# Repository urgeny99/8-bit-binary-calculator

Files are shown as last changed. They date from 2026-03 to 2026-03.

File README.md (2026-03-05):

# 8-bit-binary-calculator
## This is an 8-bit adder that adds two 8-bit numbers together (255+255).

### How It Works & Parts Used:

- 4x quad XOR gates (SN74HC86)
- 4x quad AND gates (SN74HC08)
- 2x quad OR gates (SN74HC32)
- 2x DIP switch x08
- 11x Decoupling capacitors 
- 9x single color LEDs for showing the output
- 25x resistors for setting switches Low and protecting LEDs (9x 1k; 16x 100k)
- 1x screw terminal for connecting to power

#### HOW IT WORKS

The adder works by having 8 + 8 inputs (A0-A7; B0-B7) and taking them into half and full adders.
Use the DIP-switches to set the input values, and read LED output.
The Half adder looks like this | And this is a Full adder 
:------:|:---------:
 | 



# BOM



Shematic   | PCB | 3D model
:-------------:|:-----------:|:-----------:
 |  |

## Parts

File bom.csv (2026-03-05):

Designator | Footprint | Quantity | Value | LCSC Part # | Link to parts
AND1, AND2, AND3, AND4 | SO-14_3.9x8.65mm_P1.27mm | 4 | SN74HC08N | C5217243 | https://www.lcsc.com/product-detail/C5217243.html
C1, C11, C2, C3, C4, C5, C6, C7, C8, C9 | 0603 | 10 | 0.1uF | C14663 | https://www.lcsc.com/product-detail/C14663.html
C10 | 0603 | 1 | 10uF | C19702 | https://www.lcsc.com/product-detail/C19702.html
D1, D2, D3, D4, D5, D6, D7, D8, D9 | 0805 | 9 | LED | C84260 | https://www.lcsc.com/product-detail/C84260.html
J1 | TerminalBlock_Phoenix_MKDS-1,5-2-5.08_1x02_P5.08mm_Horizontal | 1 | Screw_Terminal_01x02 | C5183929 | https://www.lcsc.com/product-detail/C5183929.html
OR1, OR2 | SO-14_3.9x8.65mm_P1.27mm | 2 | SN74HC32N | C2869657 | https://www.lcsc.com/product-detail/C2869657.html
R1, R2, R3, R4, R5, R6, R7, R8, R9 | 0603 | 9 | 1k | C22548 | https://www.lcsc.com/product-detail/C22548.html
R10, R11, R12, R13, R14, R15, R16, R17, R18, R19, R20, R21, R22, R23, R24, R25 | 0603 | 16 | 100k | C14675 | https://www.lcsc.com/product-detail/C14675.html
SW1, SW2 | SW_DIP_SPSTx08_Slide_9.78x22.5mm_W7.62mm_P2.54mm | 2 | SW_DIP_x08 | no Parts found
XOR1, XOR2, XOR3, XOR4 | SO-14_3.9x8.65mm_P1.27mm | 4 | SN74HC86N | C2860577 | https://www.lcsc.com/product-detail/C2860577.html

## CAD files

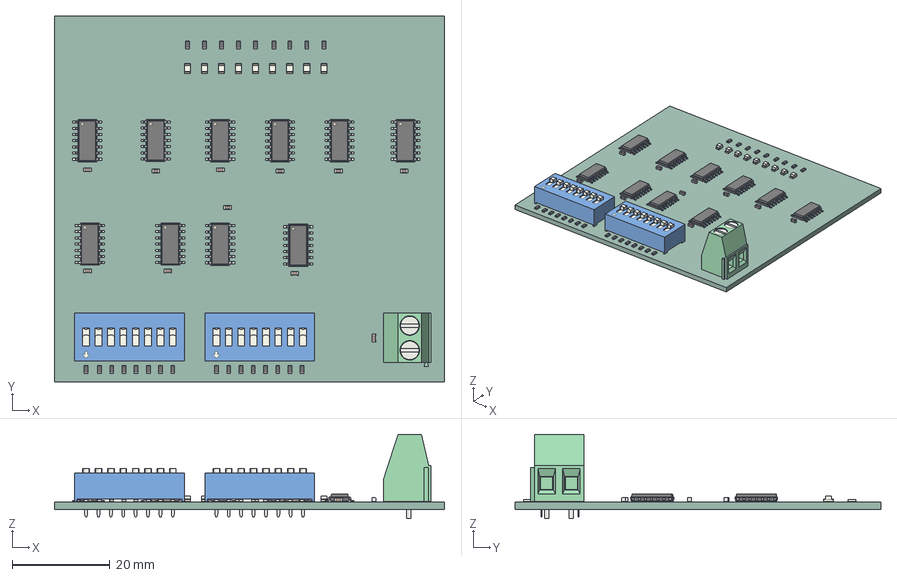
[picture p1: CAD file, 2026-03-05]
PCB-Design/8-bit calculator.step
80.0 x 75.0 x 17.3 mm
LED_0805_2012Metric x 9
R_0603_1608Metric x 25
SO-14_3.9x8.65mm_P1.27mm x 10
SW_DIP_SPSTx08_Slide_9.78x22.5mm_W7.62mm_P2.54mm x 2
TerminalBlock_Phoenix_MKDS-1,5-2-5.08_1x02_P5.08mm_Horizontal
C_0603_1608Metric x 11
8-bit calculator_PCB

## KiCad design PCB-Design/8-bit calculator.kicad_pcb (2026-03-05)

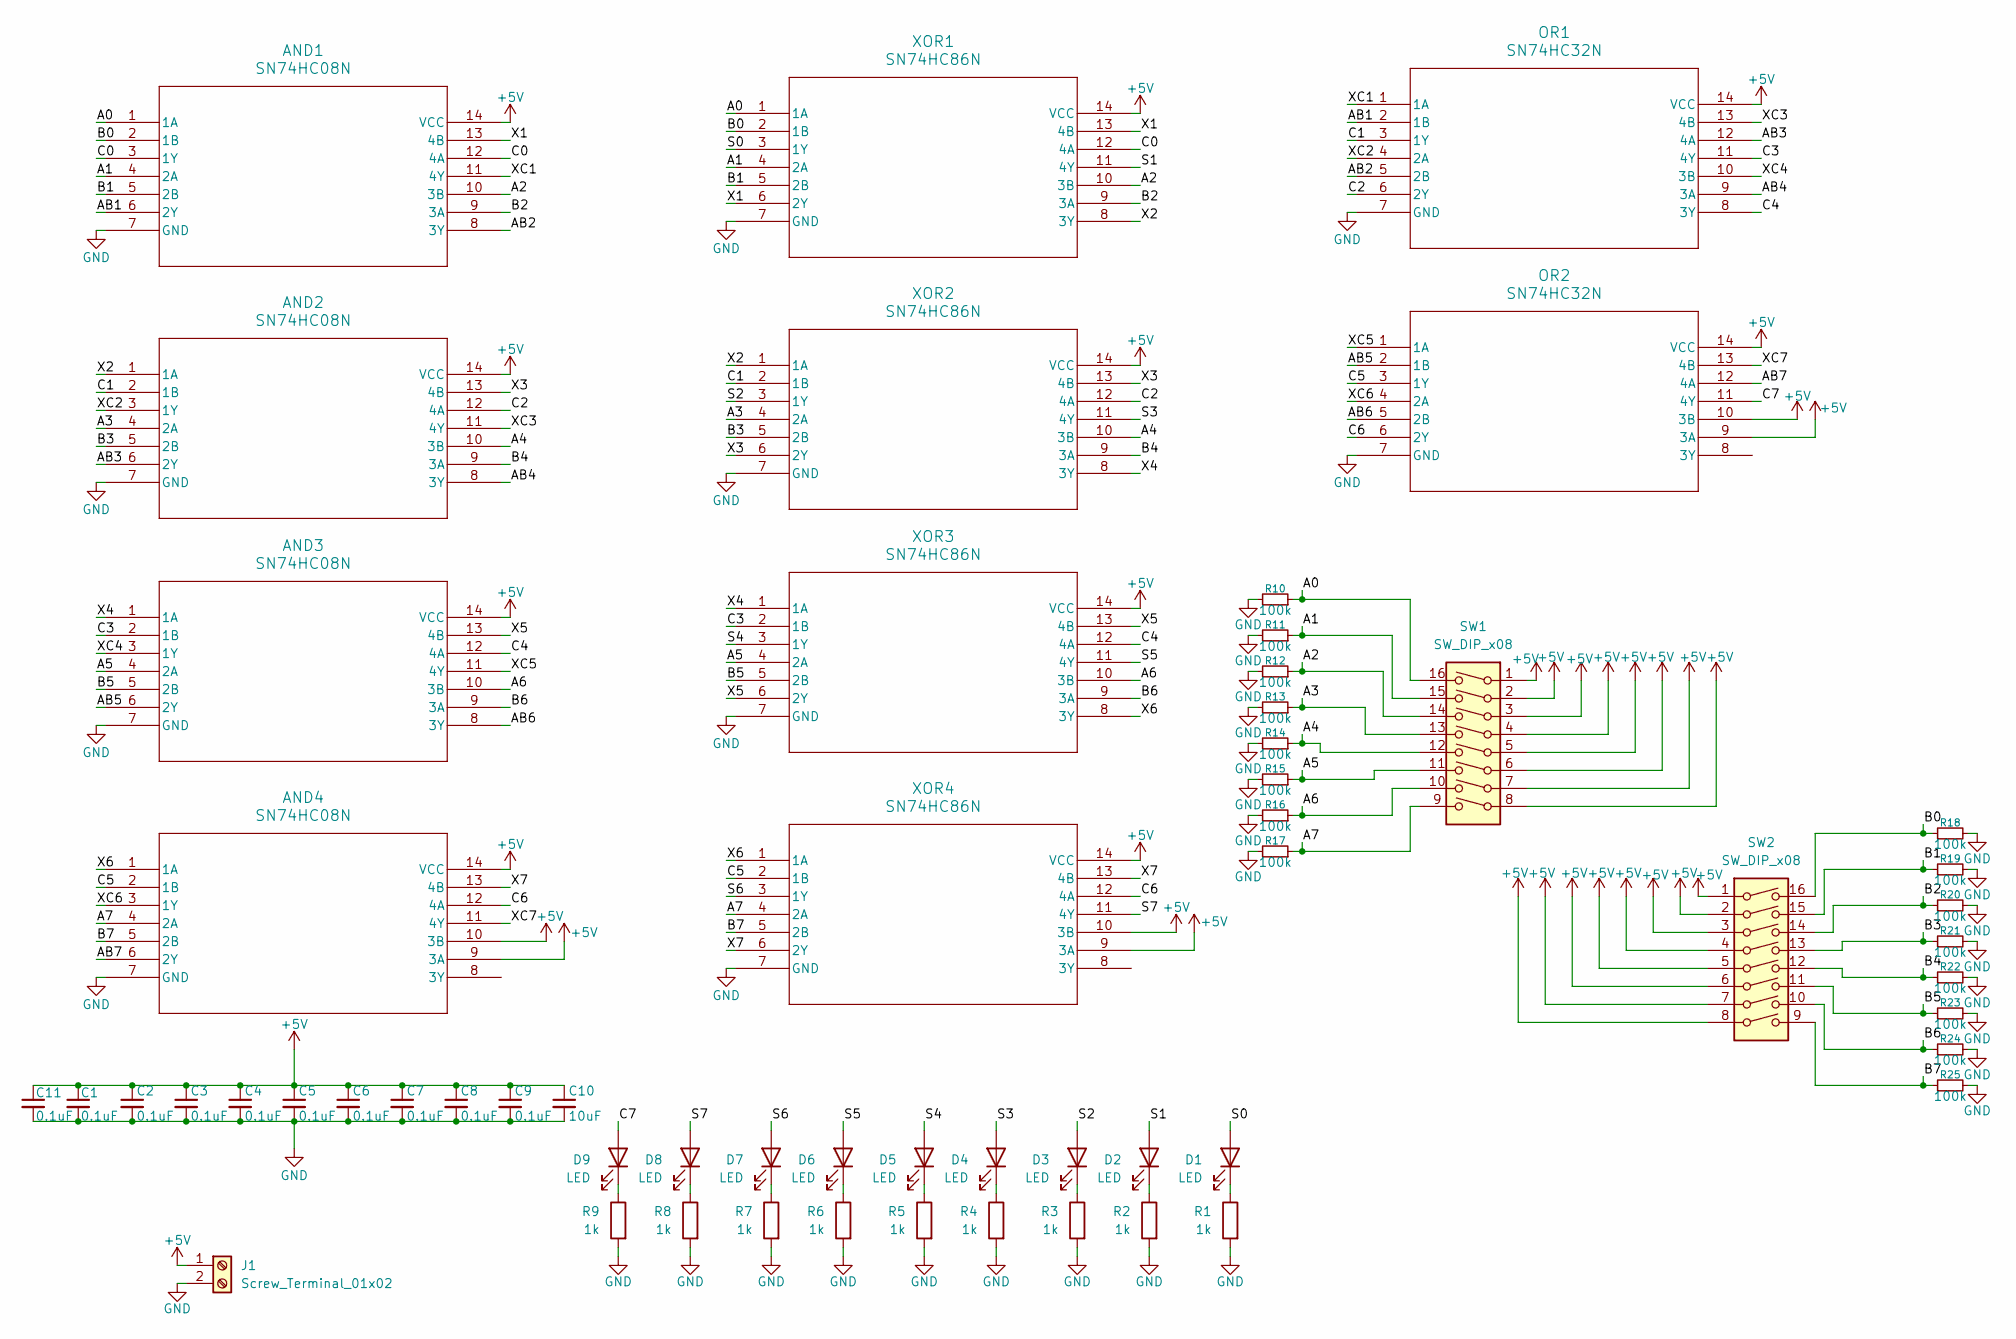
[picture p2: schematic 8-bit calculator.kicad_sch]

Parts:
AND1, AND2, AND3, AND4: SN74HC08N; SO-14_3.9x8.65mm_P1.27mm
C1, C2, C3, C4, C5, C6, C7, C8, C9, C11: 0.1uF; C_0603_1608Metric
C10: 10uF; C_0603_1608Metric
D1, D2, D3, D4, D5, D6, D7, D8, D9: LED; LED_0805_2012Metric
J1: Screw_Terminal_01x02; TerminalBlock_Phoenix_MKDS-1,5-2-5.08_1x02_P5.08mm_Horizont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
OR1, OR2: SN74HC32N; SO-14_3.9x8.65mm_P1.27mm
R1, R2, R3, R4, R5, R6, R7, R8, R9: 1k; R_0603_1608Metric
R10, R11, R12, R13, R14, R15, R16, R17, R18, R19, R20, R21, R22, R23, R24, R25: 100k; R_0603_1608Metric
SW1, SW2: SW_DIP_x08; SW_DIP_SPSTx08_Slide_9.78x22.5mm_W7.62mm_P2.54mm
XOR1, XOR2, XOR3, XOR4: SN74HC86N; SO-14_3.9x8.65mm_P1.27mm

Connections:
+5V: AND1.14 (VCC), AND2.14 (VCC), AND3.14 (VCC), AND4.9 (3A), AND4.10 (3B), AND4.14 (VCC), C1.1, C2.1, C3.1, C4.1, C5.1, C6.1, C7.1, C8.1, C9.1, C10.1, C11.1, J1.1, OR1.14 (VCC), OR2.9 (3A), OR2.10 (3B), OR2.14 (VCC), SW1.1, SW1.2, SW1.3, SW1.4, SW1.5, SW1.6, SW1.7, SW1.8, SW2.1, SW2.2, SW2.3, SW2.4, SW2.5, SW2.6, SW2.7, SW2.8, XOR1.14 (VCC), XOR2.14 (VCC), XOR3.14 (VCC), XOR4.9 (3A), XOR4.10 (3B), XOR4.14 (VCC)
/A0: AND1.1 (1A), R10.1, SW1.16, XOR1.1 (1A)
/A1: AND1.4 (2A), R11.1, SW1.15, XOR1.4 (2A)
/A2: AND1.10 (3B), R12.1, SW1.14, XOR1.10 (3B)
/A3: AND2.4 (2A), R13.1, SW1.13, XOR2.4 (2A)
/A4: AND2.10 (3B), R14.1, SW1.12, XOR2.10 (3B)
/A5: AND3.4 (2A), R15.1, SW1.11, XOR3.4 (2A)
/A6: AND3.10 (3B), R16.1, SW1.10, XOR3.10 (3B)
/A7: AND4.4 (2A), R17.1, SW1.9, XOR4.4 (2A)
/AB1: AND1.6 (2Y), OR1.2 (1B)
/AB2: AND1.8 (3Y), OR1.5 (2B)
/AB3: AND2.6 (2Y), OR1.12 (4A)
/AB4: AND2.8 (3Y), OR1.9 (3A)
/AB5: AND3.6 (2Y), OR2.2 (1B)
/AB6: AND3.8 (3Y), OR2.5 (2B)
/AB7: AND4.6 (2Y), OR2.12 (4A)
/B0: AND1.2 (1B), R18.1, SW2.16, XOR1.2 (1B)
/B1: AND1.5 (2B), R19.1, SW2.15, XOR1.5 (2B)
/B2: AND1.9 (3A), R20.1, SW2.14, XOR1.9 (3A)
/B3: AND2.5 (2B), R21.1, SW2.13, XOR2.5 (2B)
/B4: AND2.9 (3A), R22.1, SW2.12, XOR2.9 (3A)
/B5: AND3.5 (2B), R23.1, SW2.11, XOR3.5 (2B)
/B6: AND3.9 (3A), R24.1, SW2.10, XOR3.9 (3A)
/B7: AND4.5 (2B), R25.1, SW2.9, XOR4.5 (2B)
/C0: AND1.3 (1Y), AND1.12 (4A), XOR1.12 (4A)
/C1: AND2.2 (1B), OR1.3 (1Y), XOR2.2 (1B)
/C2: AND2.12 (4A), OR1.6 (2Y), XOR2.12 (4A)
/C3: AND3.2 (1B), OR1.11 (4Y), XOR3.2 (1B)
/C4: AND3.12 (4A), OR1.8 (3Y), XOR3.12 (4A)
/C5: AND4.2 (1B), OR2.3 (1Y), XOR4.2 (1B)
/C6: AND4.12 (4A), OR2.6 (2Y), XOR4.12 (4A)
/C7: D9.2 (A), OR2.11 (4Y)
/S0: D1.2 (A), XOR1.3 (1Y)
/S1: D2.2 (A), XOR1.11 (4Y)
/S2: D3.2 (A), XOR2.3 (1Y)
/S3: D4.2 (A), XOR2.11 (4Y)
/S4: D5.2 (A), XOR3.3 (1Y)
/S5: D6.2 (A), XOR3.11 (4Y)
/S6: D7.2 (A), XOR4.3 (1Y)
/S7: D8.2 (A), XOR4.11 (4Y)
/X1: AND1.13 (4B), XOR1.6 (2Y), XOR1.13 (4B)
/X2: AND2.1 (1A), XOR1.8 (3Y), XOR2.1 (1A)
/X3: AND2.13 (4B), XOR2.6 (2Y), XOR2.13 (4B)
/X4: AND3.1 (1A), XOR2.8 (3Y), XOR3.1 (1A)
/X5: AND3.13 (4B), XOR3.6 (2Y), XOR3.13 (4B)
/X6: AND4.1 (1A), XOR3.8 (3Y), XOR4.1 (1A)
/X7: AND4.13 (4B), XOR4.6 (2Y), XOR4.13 (4B)
/XC1: AND1.11 (4Y), OR1.1 (1A)
/XC2: AND2.3 (1Y), OR1.4 (2A)
/XC3: AND2.11 (4Y), OR1.13 (4B)
/XC4: AND3.3 (1Y), OR1.10 (3B)
/XC5: AND3.11 (4Y), OR2.1 (1A)
/XC6: AND4.3 (1Y), OR2.4 (2A)
/XC7: AND4.11 (4Y), OR2.13 (4B)
GND: AND1.7 (GND), AND2.7 (GND), AND3.7 (GND), AND4.7 (GND), C1.2, C2.2, C3.2, C4.2, C5.2, C6.2, C7.2, C8.2, C9.2, C10.2, C11.2, J1.2, OR1.7 (GND), OR2.7 (GND), R1.2, R2.2, R3.2, R4.2, R5.2, R6.2, R7.2, R8.2, R9.2, R10.2, R11.2, R12.2, R13.2, R14.2, R15.2, R16.2, R17.2, R18.2, R19.2, R20.2, R21.2, R22.2, R23.2, R24.2, R25.2, XOR1.7 (GND), XOR2.7 (GND), XOR3.7 (GND), XOR4.7 (GND)
unnamed: D1.1 (K), R1.1
unnamed: D2.1 (K), R2.1
unnamed: D3.1 (K), R3.1
unnamed: D4.1 (K), R4.1
unnamed: D5.1 (K), R5.1
unnamed: D6.1 (K), R6.1
unnamed: D7.1 (K), R7.1
unnamed: D8.1 (K), R8.1
unnamed: D9.1 (K), R9.1

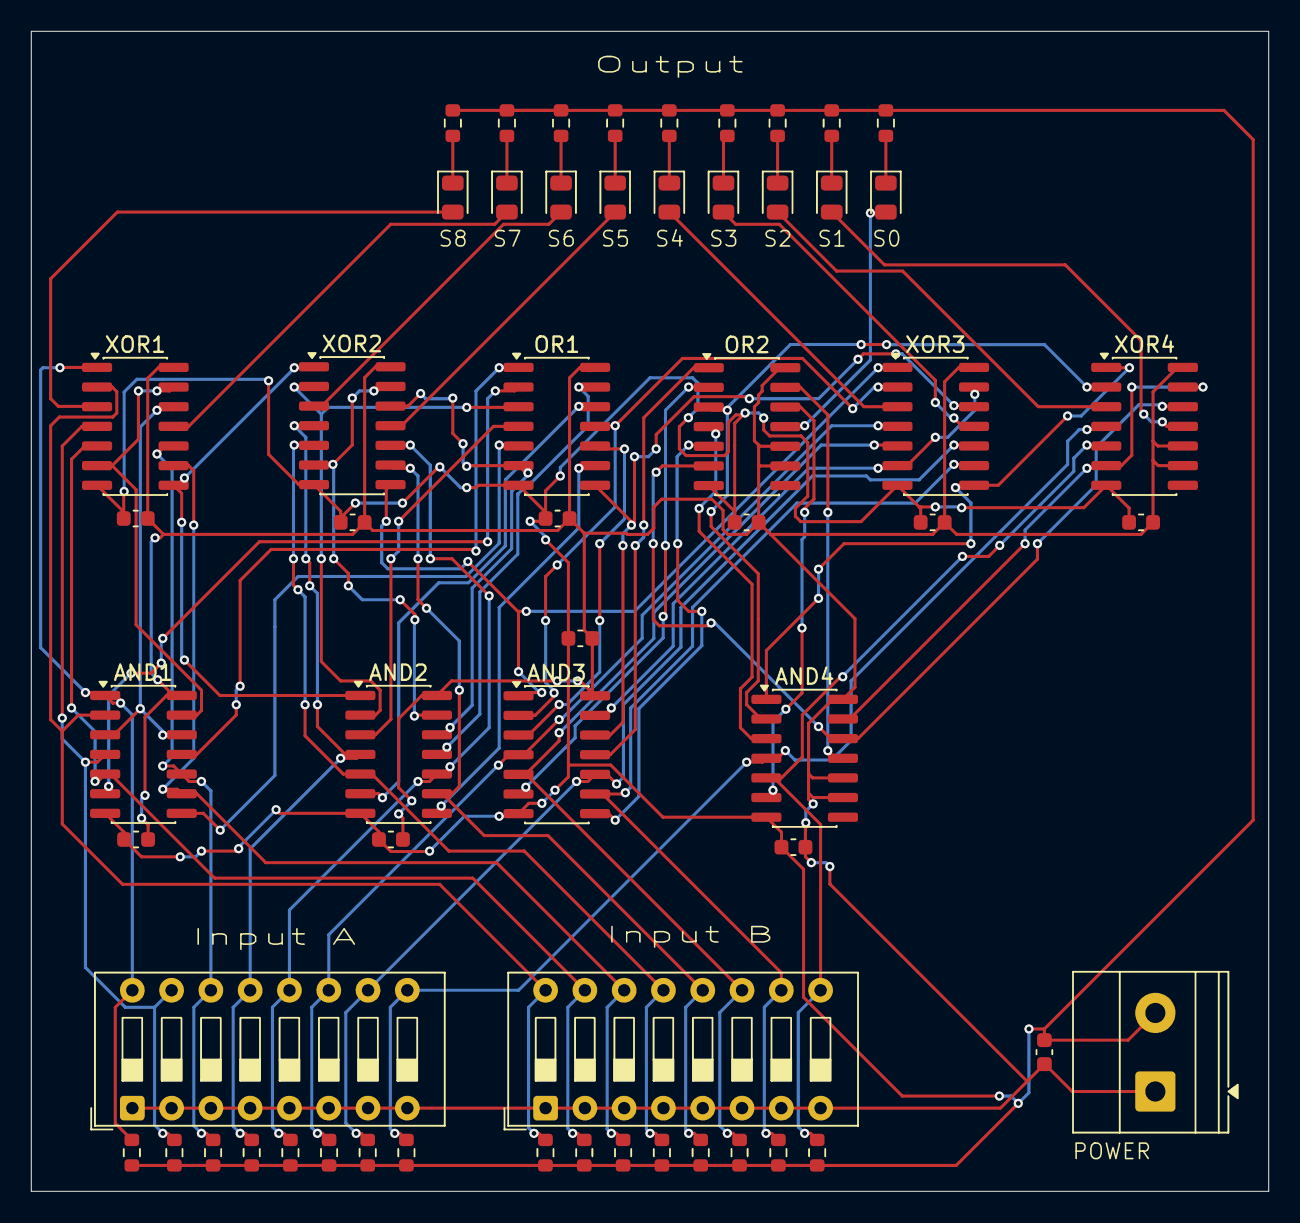
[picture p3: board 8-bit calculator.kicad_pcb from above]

Board: 2 copper layers, 80.0 x 75.0 mm, 58 parts (0 on the bottom side), 64 nets.

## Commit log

2026-03-05 Clean up bom.csv formatting and remove empty lines
    Removed empty lines and adjusted formatting for consistency.
    [bom.csv]
2026-03-05 Refactor bom.csv for formatting consistency
    Removed empty lines and adjusted formatting.
    [bom.csv]
2026-03-05 Clean up bom.csv formatting and add missing commas
    Removed extra blank lines and added commas at the end of some lines.
    [bom.csv]
2026-03-05 Fix formatting issues in bom.csv
    [bom.csv]
2026-03-05 Clean up bom.csv formatting and remove blanks
    Removed extra blank lines and ensured consistent formatting.
    [bom.csv]
2026-03-05 Fix BOM formatting and add missing parts
    [bom.csv]
2026-03-05 Fix formatting and add missing URLs in bom.csv
    [bom.csv]
